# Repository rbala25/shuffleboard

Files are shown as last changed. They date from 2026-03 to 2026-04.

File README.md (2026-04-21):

# Shuffleboard

60 FPS multiplayer shuffleboard built on bare-metal C/C++ for the TM4C123 — no OS, no shortcuts. ECE319H Final Project.

---

## Highlights

**Comparator + FET Input Detection** — Puck sensing uses a custom analog comparator circuit driving an N-channel FET, with hardware debouncing and firmware-level input validation. Fast, noise-resistant, and doesn't rely on polling.

**Custom DAC + Audio** — Sound effects generated through an R-2R resistor ladder DAC feeding a discrete amplifier and speaker.

**SPI Display Pipeline** — ST7735 TFT screen handles all game state rendering and animations via SPI. Score output runs in parallel on 7-segment displays driven by 74HC595 shift registers.

**Game Loop & State Machine** — Fully interrupt-driven architecture managing turn logic, collision validation, and score tracking in real time. All rendering, input, and audio synchronized to a 60 FPS Timer12 interrupt — no RTOS, no scheduler.

**Mixed-Signal PCB** — Custom board with split digital/analog ground planes, decoupling for stable SPI, and an integrated comparator/FET sensing front-end alongside the DAC output stage.

---

## Stack

| Layer | Tech |
|---|---|
| MCU | TM4C123GXL (ARM Cortex-M4) |
| Language | C/C++, bare-metal |
| Display | ST7735 TFT over SPI |
| Score Display | 7-segment + 74HC595 shift registers |
| Audio | R-2R DAC + speaker amp |
| Input | Analog comparator + N-FET + hardware debounce |

---

Developed for **ECE319H — Introduction to Embedded Systems (Honors)** at The University of Texas at Austin.

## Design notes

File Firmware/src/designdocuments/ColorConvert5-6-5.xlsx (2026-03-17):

red | green | blue | 565
0 | 255 | 120 | 0x7FE0 | 0x7FE0, // 0, 255, 120

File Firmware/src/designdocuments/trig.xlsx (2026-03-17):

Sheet: 64
 | 2 |  | 64
angle | vx | vy | ix | iy
0 | 2 | 0 | 128 | 0
0.09817477042 | 1.990369453 | 0.1960342807 | 127 | 13
0.1963495408 | 1.961570561 | 0.390180644 | 126 | 25
0.2945243113 | 1.913880671 | 0.5805693545 | 122 | 37
0.3926990817 | 1.847759065 | 0.7653668647 | 118 | 49
0.4908738521 | 1.763842529 | 0.9427934737 | 113 | 60
0.5890486225 | 1.662939225 | 1.111140466 | 106 | 71
0.687223393 | 1.546020907 | 1.268786568 | 99 | 81
0.7853981634 | 1.414213562 | 1.414213562 | 91 | 91
0.8835729338 | 1.268786568 | 1.546020907 | 81 | 99
0.9817477042 | 1.111140466 | 1.662939225 | 71 | 106
1.079922475 | 0.9427934737 | 1.763842529 | 60 | 113
1.178097245 | 0.7653668647 | 1.847759065 | 49 | 118
1.276272016 | 0.5805693545 | 1.913880671 | 37 | 122
1.374446786 | 0.390180644 | 1.961570561 | 25 | 126
1.472621556 | 0.1960342807 | 1.990369453 | 13 | 127
1.570796327 | -7.656635742e-16 | 2 | 0 | 128
1.668971097 | -0.1960342807 | 1.990369453 | -13 | 127
1.767145868 | -0.390180644 | 1.961570561 | -25 | 126
1.865320638 | -0.5805693545 | 1.913880671 | -37 | 122
1.963495408 | -0.7653668647 | 1.847759065 | -49 | 118
2.061670179 | -0.9427934737 | 1.763842529 | -60 | 113
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

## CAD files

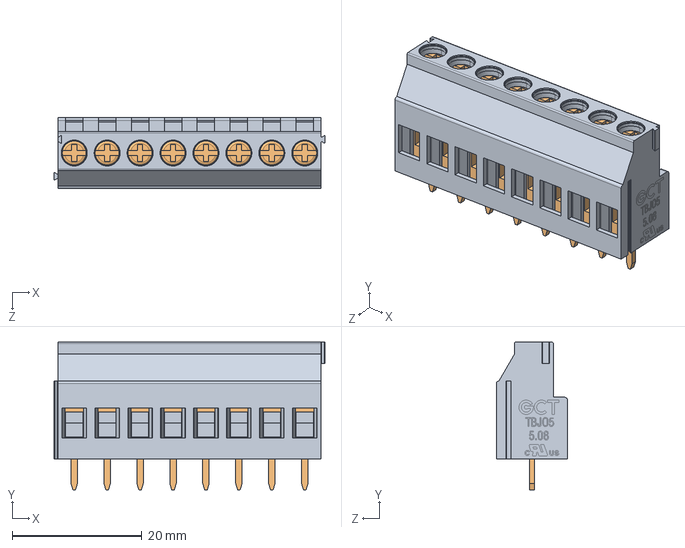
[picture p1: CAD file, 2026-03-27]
Hardware/Shuffleboard/SpecificParts/3D/TBJ05-08-1-G-G.stp
41.8 x 22.8 x 11.0 mm

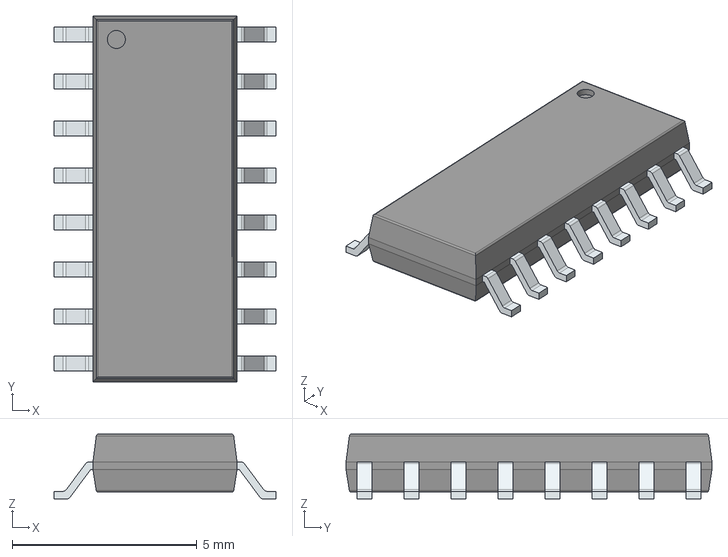
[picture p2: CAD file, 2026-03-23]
Hardware/Shuffleboard/SpecificParts/3D/74HC595D_BJ_.stp
6.00 x 9.90 x 1.75 mm
PinsArrayLR

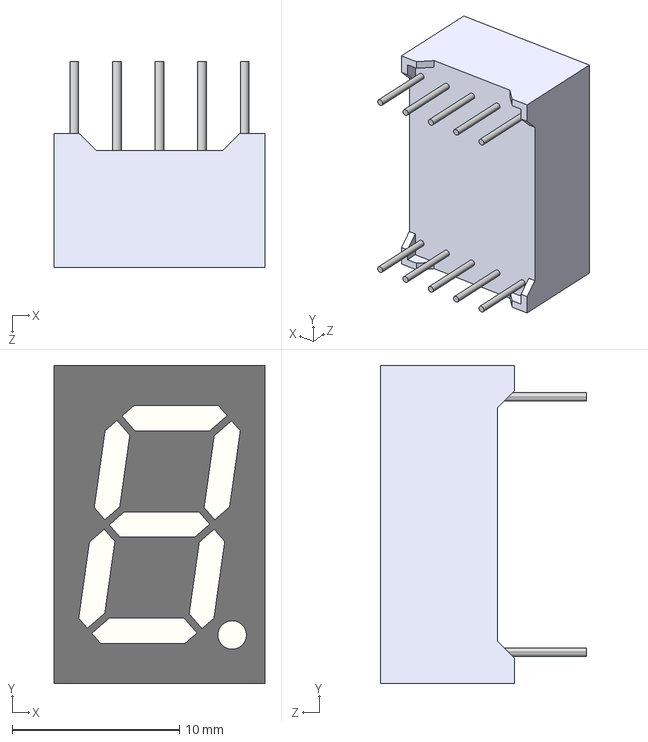
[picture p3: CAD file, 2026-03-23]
Hardware/Shuffleboard/SpecificParts/3D/INND-TS56RCB.stp
12.6 x 19.0 x 12.3 mm

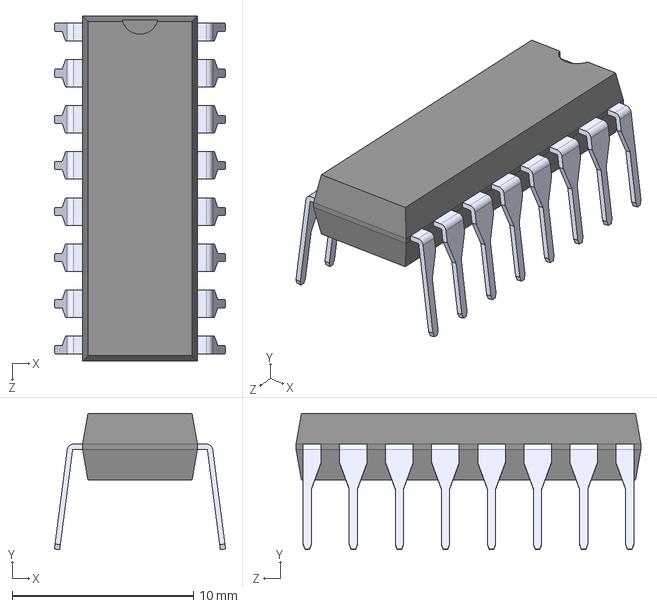
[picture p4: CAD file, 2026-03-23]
Hardware/Shuffleboard/SpecificParts/3D/LOGIC-74HC595N_DIP16_.step
9.44 x 7.53 x 19.0 mm

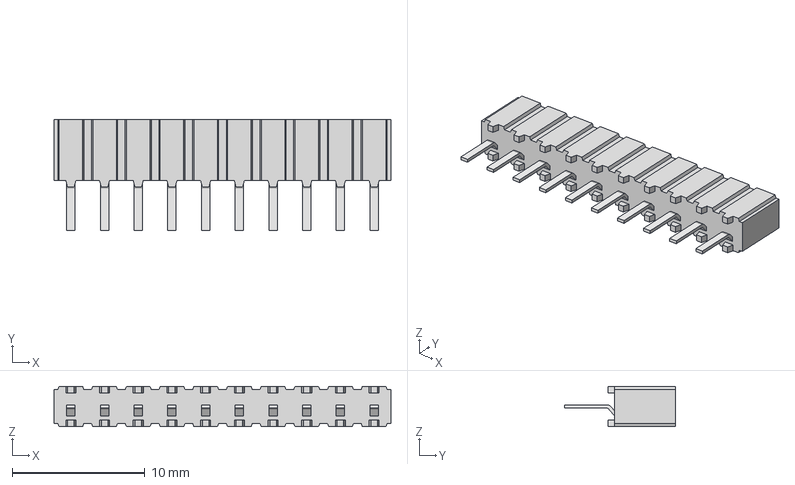
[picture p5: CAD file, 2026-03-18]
Hardware/Shuffleboard/SpecificParts/3D/CES-110-01-G-S.stp
25.4 x 8.33 x 3.05 mm
CES-110-01-S_socket
011001TS
011001TS2

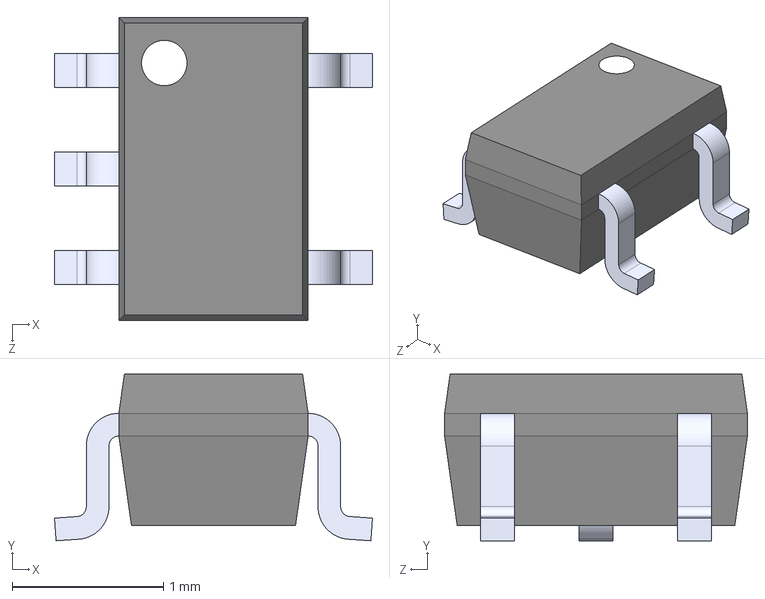
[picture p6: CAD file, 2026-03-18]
Hardware/Shuffleboard/SpecificParts/3D/LMV331M7.STEP
2.10 x 1.10 x 2.00 mm

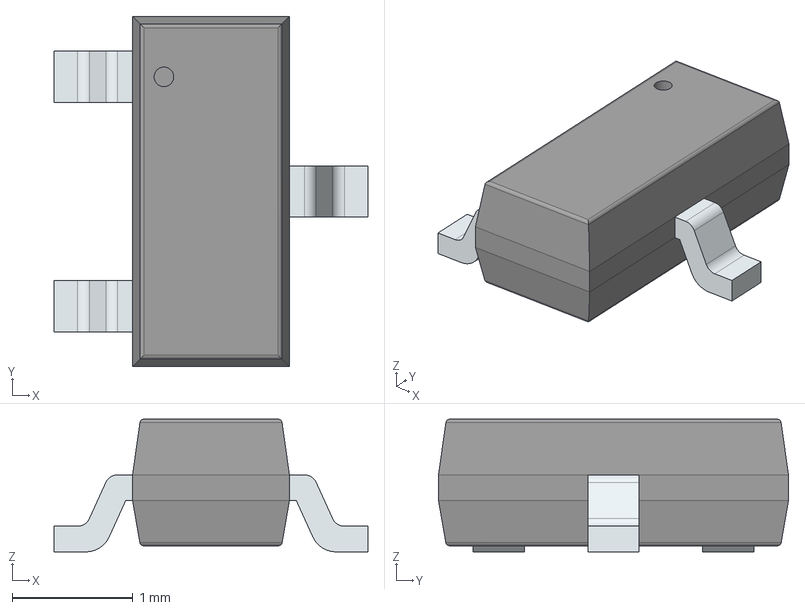
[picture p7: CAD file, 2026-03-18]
Hardware/Shuffleboard/SpecificParts/3D/2N7002_H6327.stp
2.60 x 2.90 x 1.10 mm
PinsArrayL
FilletPinR

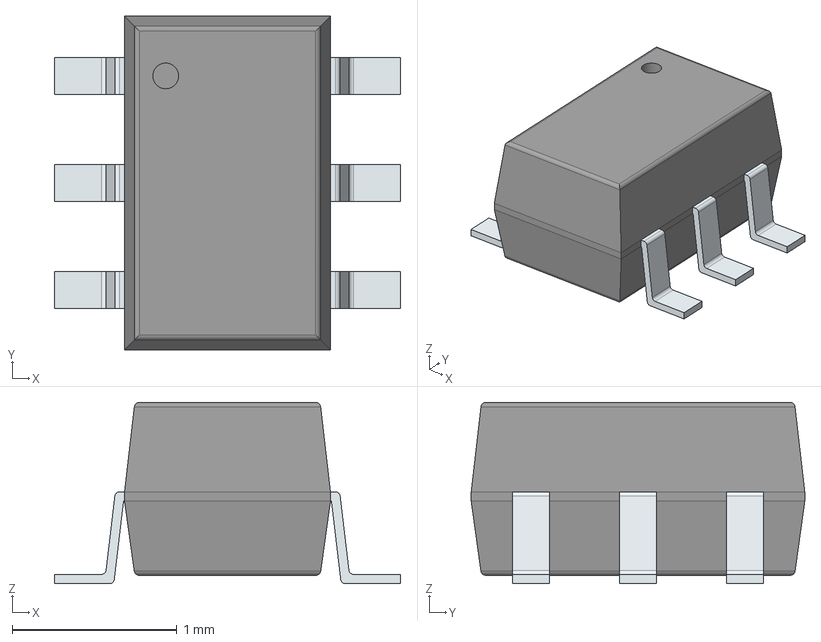
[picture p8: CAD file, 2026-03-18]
Hardware/Shuffleboard/SpecificParts/3D/DG3157EDL-T1-GE3.stp
2.10 x 2.02 x 1.10 mm
PinsArrayLR

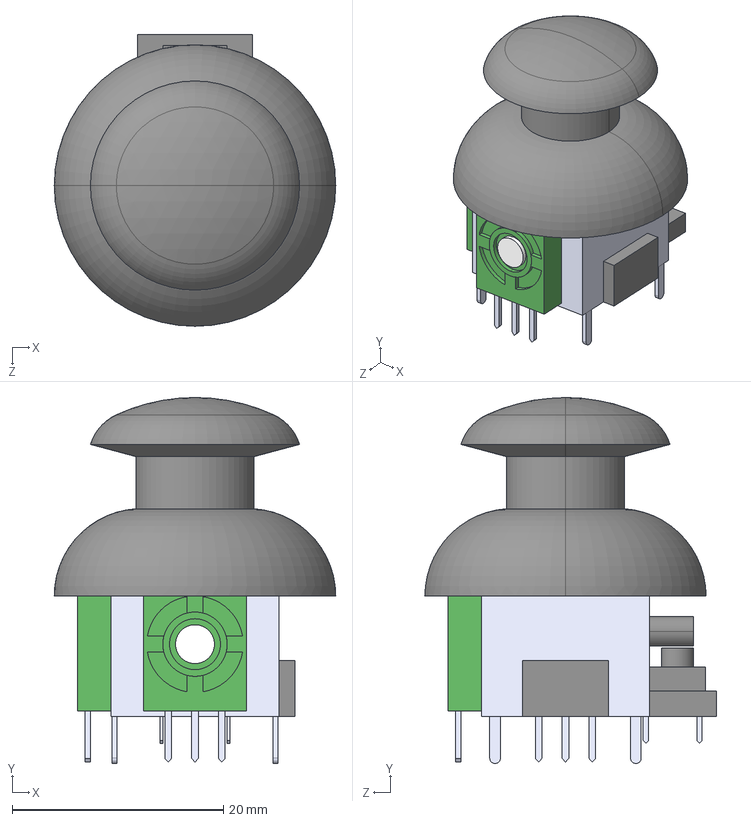
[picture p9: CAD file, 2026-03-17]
Hardware/Shuffleboard/SpecificParts/3D/COM-09032.step
26.7 x 34.7 x 27.6 mm

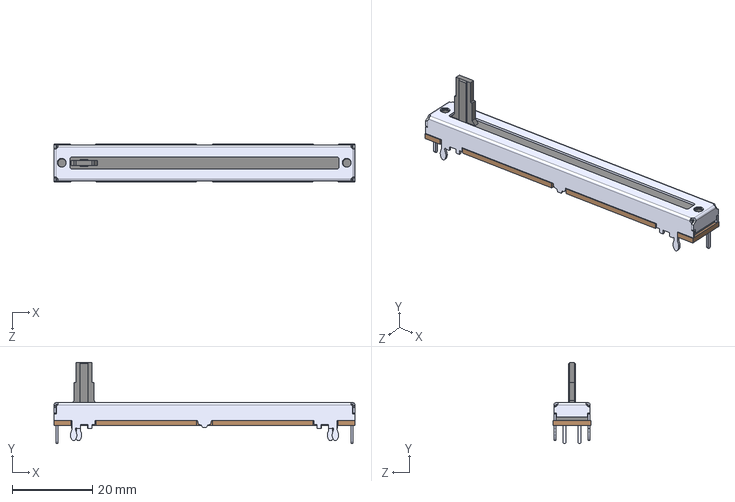
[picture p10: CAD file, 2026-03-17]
Hardware/Shuffleboard/SpecificParts/3D/PTA6043-2010CIA203.STEP
75.0 x 20.2 x 9.40 mm

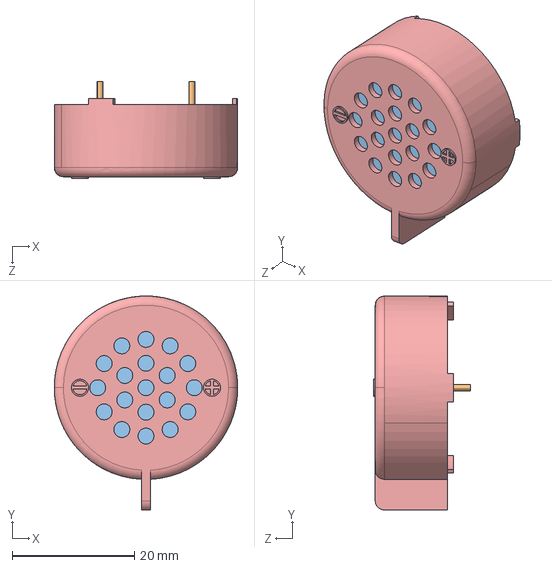
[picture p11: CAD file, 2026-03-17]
Hardware/Shuffleboard/SpecificParts/3D/CMS-3012-18T.STEP
30.0 x 35.0 x 15.9 mm

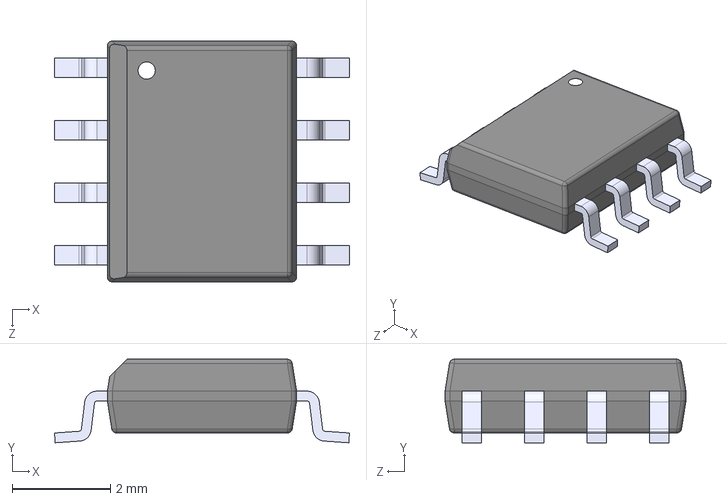
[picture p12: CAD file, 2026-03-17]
Hardware/Shuffleboard/SpecificParts/3D/PAM8302AADCR.step
6.00 x 1.70 x 4.90 mm

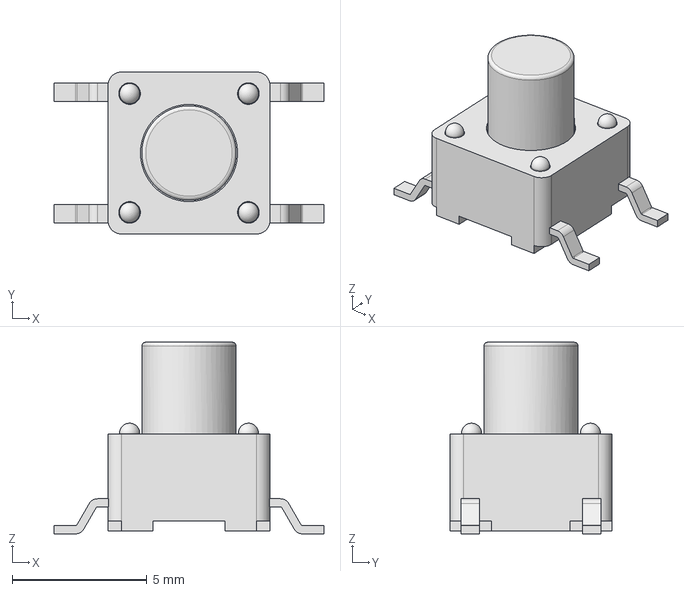
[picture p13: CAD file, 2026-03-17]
Hardware/Shuffleboard/SpecificParts/3D/TL3301FF160QG.STEP
10.0 x 6.00 x 7.10 mm

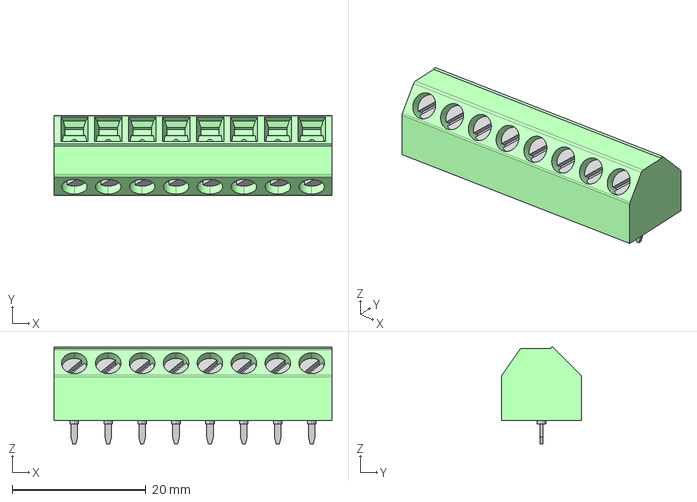
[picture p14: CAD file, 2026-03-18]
Hardware/Shuffleboard/SpecificParts/3D/1869279.stp
41.6 x 12.0 x 14.5 mm

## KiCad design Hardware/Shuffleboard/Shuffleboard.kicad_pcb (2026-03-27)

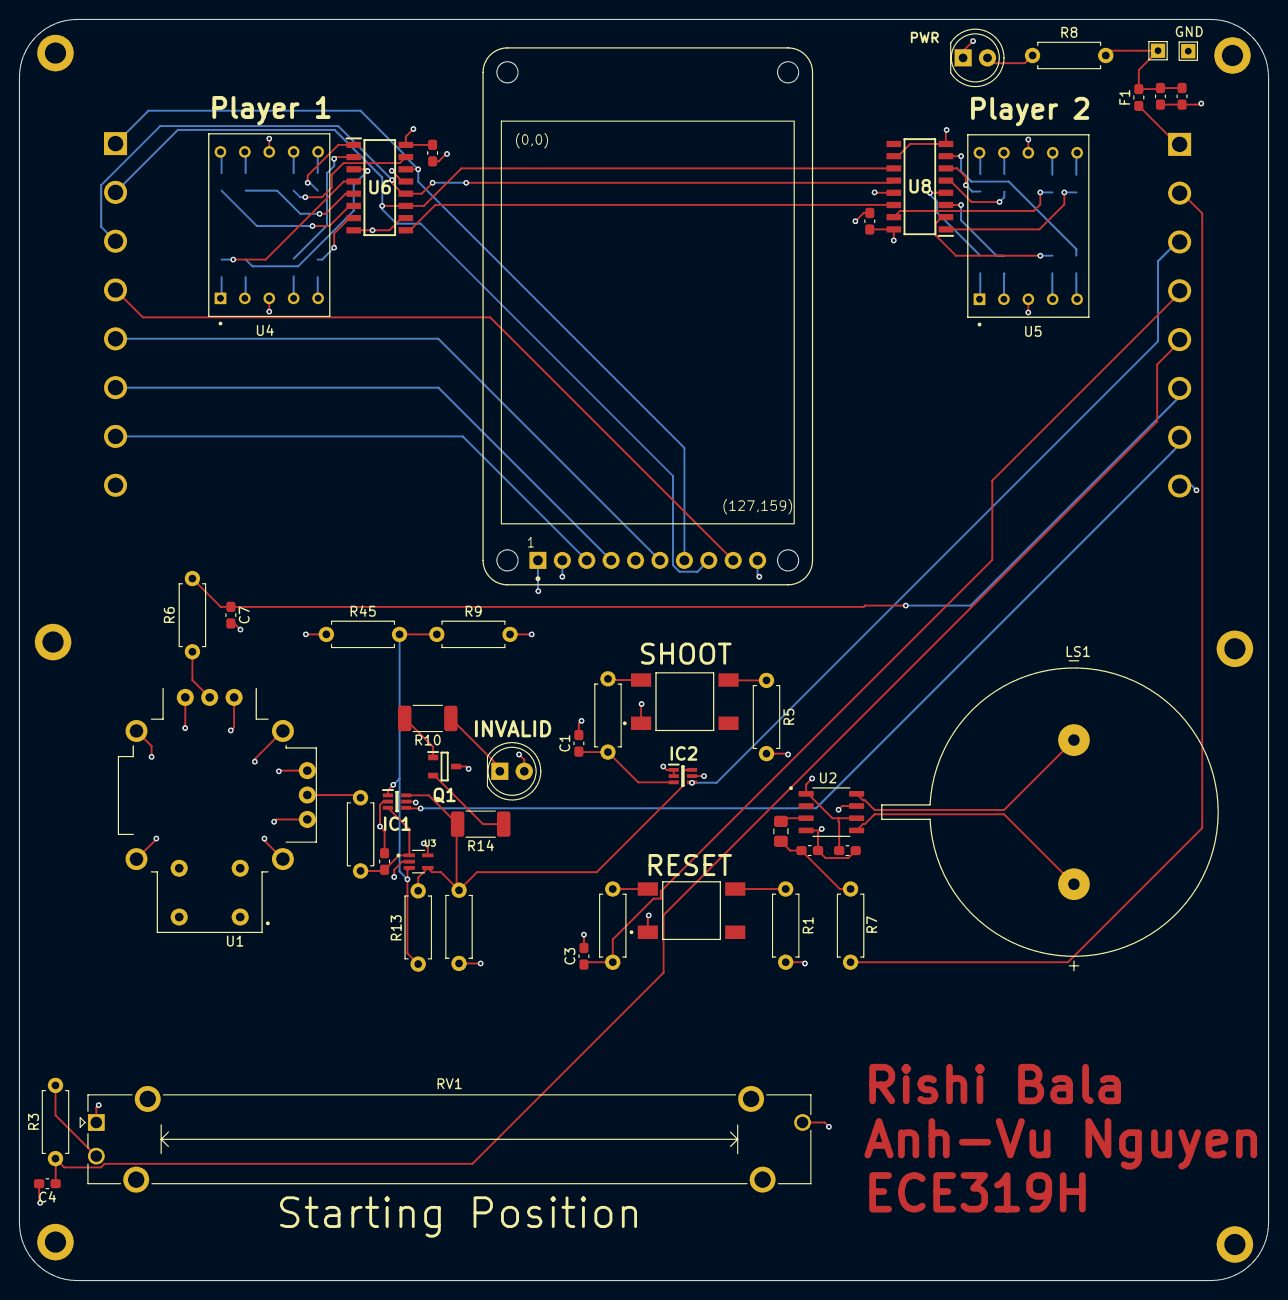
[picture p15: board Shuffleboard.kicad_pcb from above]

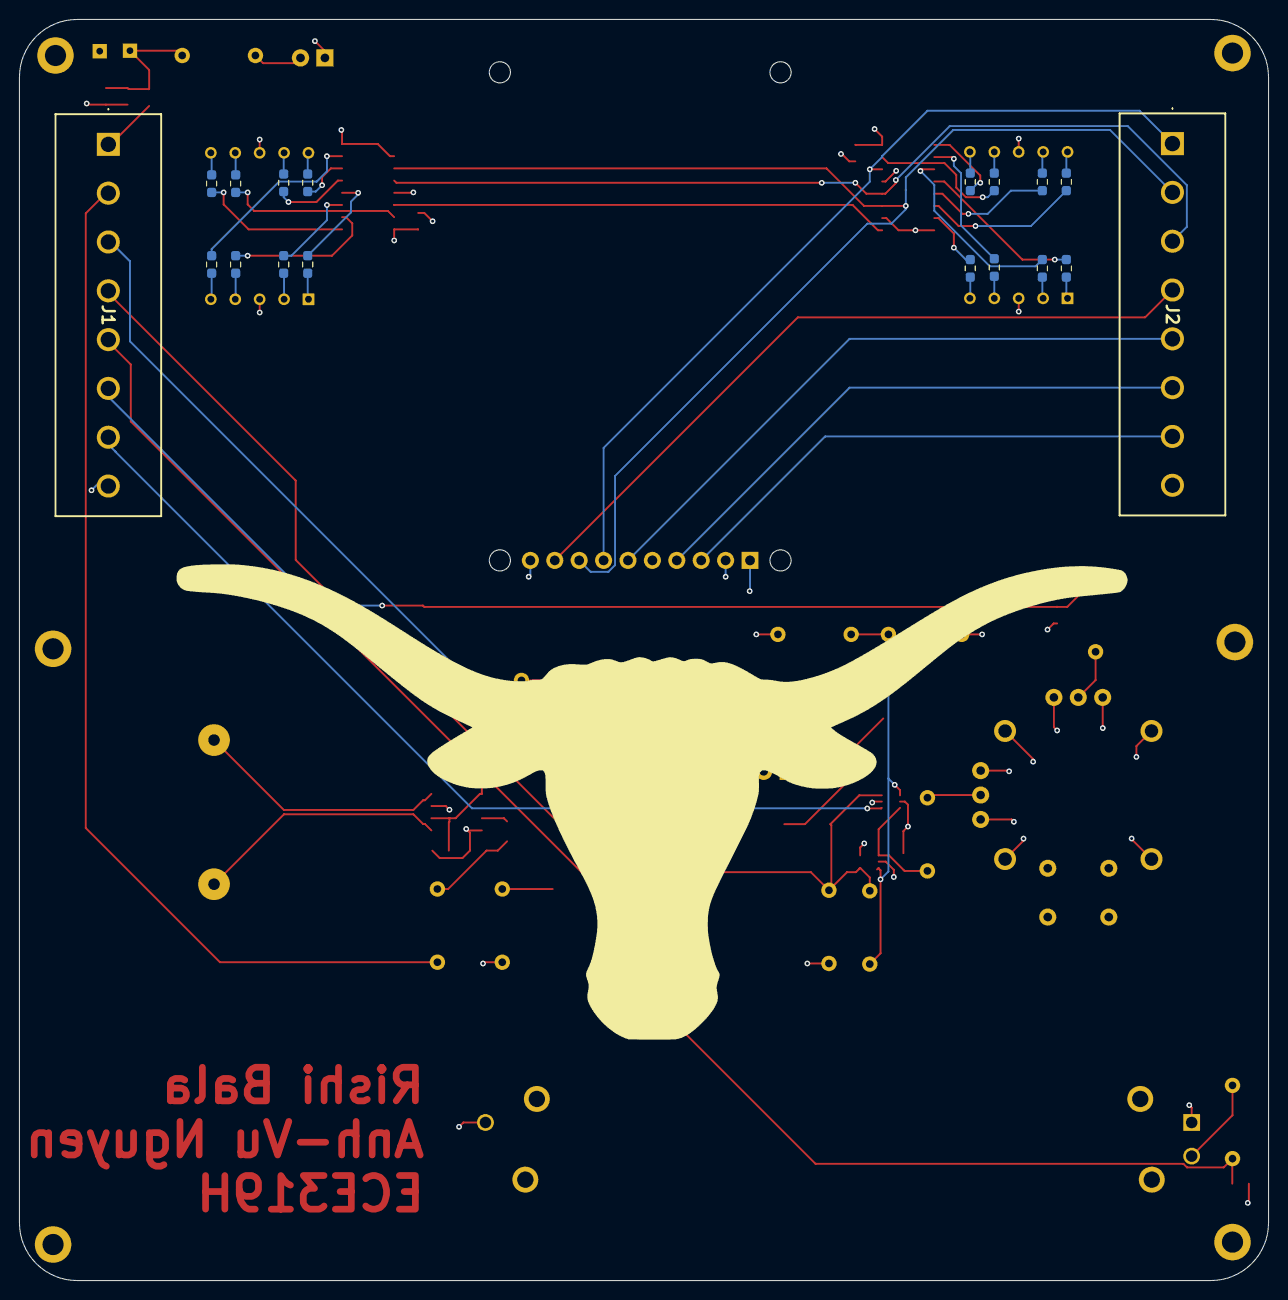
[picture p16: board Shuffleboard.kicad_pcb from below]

Board: 4 copper layers, 130.0 x 131.2 mm, 71 parts (18 on the bottom side), 68 nets.

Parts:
C1, C2, C3, C4, C5, C6, C7, C8, C10, C11, C12: 100n; C_0603_1608Metric_Pad1.08x0.95mm_HandSolder
C9: 1u; C_0805_2012Metric_Pad1.18x1.45mm_HandSolder
D1: Red; LED_D5.0mm
D32: Green; LED_D5.0mm
F1: Fuse_0603_1608Metric_Pad1.05x0.95mm_HandSolder
H1, H2, H3, H4, H5, H6: MountingHole_2.2mm_M2_DIN965_Pad
IC1, IC2: SOT65P210X110-6N
J1, J2: TBJ05-08-1-G-G; TBJ05081GG
LS1: SPKR_CMS-3012-18T
Q1: SOT95P260X110-3N
R1, R5, R9, R12, R13, R45: 10k; R_Axial_DIN0207_L6.3mm_D2.5mm_P7.62mm_Horizontal
R2, R3, R4, R6, R7, R8, R11: 1k; R_Axial_DIN0207_L6.3mm_D2.5mm_P7.62mm_Horizontal
R10, R14: 330; R_2010_5025Metric_Pad1.40x2.65mm_HandSolder
R15, R16, R17, R18, R19, R20, R21, R22, R23, R24, R25, R26, R27, R28, R29, R30: 100; R_0603_1608Metric_Pad0.98x0.95mm_HandSolder
RV1: Potentiometer_Bourns_PTA6043_Single_Slide
S1, S2: SW_TL3301FF160QG
TP1, TP2: TestPoint_THTPad_1.5x1.5mm_Drill0.7mm
U1: XDCR_COM-09032
U2: SOIC127P600X170-8N
U3: Comparator; lmv331
U4, U5: LED_INND-TS56RCB
U6, U8: SOIC127P600X175-16N
U7: adafruit_st7735r

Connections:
+3.3V: C2.1, C6.2, C10.2, C11.2, C12.1, D1.2 (A), F1.2, IC1.5 (V+), IC2.5 (V+), R8.2, R12.1, R45.1, RV1.1, S1.1, S2.1, TP2.1 (1_1), U1.H1 (H+), U1.V1 (V+), U2.1 (~SD), U2.6 (VDD), U3.5 (V+), U6.13 (G), U6.16 (VCC), U7.2 (VCC), U7.10 (LITE), U8.13 (G), U8.16 (VCC)
/3.3VIN: F1.1, J1.1
/7Seg/QH1: U6.9 (QH*), U8.14 (SER)
/Connector/HOR_PB18_ADC1_5: C7.1, J1.6, R6.2
/Connector/POS_PB17_ADC1_4: C4.1, J1.5, R3.2
/Connector/VER_PB19_ADC1_6: IC1.4 (A), J1.7
/DACOut: J1.2, R7.1
/Inputs/CompOut: IC1.6 (S), IC2.6 (S), R12.2, R13.2, R14.2, U3.4
/Inputs/SHOOT_SW: C1.1, IC2.3 (B0), R11.2
/Inputs/VER_POT: C5.1, IC1.3 (B0), R4.2, U3.1 (+)
/Inputs/Vref: IC1.1 (B1), R9.1, R13.1, R45.2, U3.3 (-)
/PA13_DC: J2.6, U7.4 (D/C)
/PB1RST: C3.1, J1.4, R2.2
/PB4SHOOT: IC2.4 (A), J1.3
/PB6_CS: J2.5, U7.6 (TFT_CS)
/PB7_MISO: J2.4, U7.9 (MISO)
/PB8_MOSI: J2.1, U6.14 (SER), U7.7 (MOSI)
/PB9_SPI_CLK: J2.2, U6.11 (SCK), U7.8 (SCK), U8.11 (SCK)
/PB15_RESET: J2.7, U7.3 (RESET)
/PB16_L/P: J2.3, U6.12 (RCK), U8.12 (RCK)
/Speaker/OUT+: LS1.P, U2.5 (OUT+)
/Speaker/OUT-: LS1.N, U2.8 (OUT-)
GND: C1.2, C2.2, C3.2, C4.2, C5.2, C6.1, C7.2, C8.2, C10.1, C11.1, C12.2, D32.1 (K), IC1.2 (GND), IC2.1 (B1), IC2.2 (GND), J1.8, J2.8, Q1.3 (S), R1.2, R5.2, R9.2, RV1.3, TP1.1 (1_1), U1.H3 (H-), U1.S1 (SHIELD), U1.S2 (SHIELD), U1.S3 (SHIELD), U1.S4 (SHIELD), U1.V3 (V-), U2.4 (IN-), U2.7 (GND), U3.2 (V-), U4.3, U4.8, U5.3, U5.8, U6.8 (GND), U6.10 (SCL), U7.1 (GND), U8.8 (GND), U8.10 (SCL)
unnamed: C8.1, C9.1, R7.2
unnamed: D1.1 (K), R10.1
unnamed: D32.2 (A), R8.1
unnamed: Q1.1 (D), R10.2
unnamed: Q1.2 (G), R14.1
unnamed: R1.1, S2.4
unnamed: R2.1, S2.3
unnamed: R3.1, RV1.2
unnamed: R5.1, S1.4
unnamed: R11.1, S1.3
unnamed: R15.2, U4.7
unnamed: R16.2, U4.6
unnamed: R17.2, U4.4
unnamed: R18.2, U4.2
unnamed: R19.2, U4.1
unnamed: R20.2, U4.9
unnamed: R21.2, U4.10
unnamed: R22.2, U4.5
unnamed: R23.2, U5.7
unnamed: R24.2, U5.6
unnamed: R25.2, U5.4
unnamed: R26.2, U5.2
unnamed: R27.2, U5.1
unnamed: R28.2, U5.9
unnamed: R29.2, U5.10
unnamed: R30.2, U5.5
unnamed: R6.1, U1.H2 (H)
unnamed: R4.1, U1.V2 (V)
unnamed: C9.2, U2.3 (IN+)
unnamed: R15.1, U6.15 (QA)
unnamed: R16.1, U6.1 (QB)
unnamed: R17.1, U6.2 (QC)
unnamed: R18.1, U6.3 (QD)
unnamed: R19.1, U6.4 (QE)
unnamed: R20.1, U6.5 (QF)
unnamed: R21.1, U6.6 (QG)
unnamed: R22.1, U6.7 (QH)
unnamed: R23.1, U8.15 (QA)
unnamed: R24.1, U8.1 (QB)
unnamed: R25.1, U8.2 (QC)
unnamed: R26.1, U8.3 (QD)
unnamed: R27.1, U8.4 (QE)
unnamed: R28.1, U8.5 (QF)
unnamed: R29.1, U8.6 (QG)
unnamed: R30.1, U8.7 (QH)

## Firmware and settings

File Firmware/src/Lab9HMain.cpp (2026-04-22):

// Lab9HMain.cpp
// Runs on MSPM0G3507
// Lab 9 ECE319H
// Anh-Vu Nguyen, Rishi Bala
// Last Modified: January 12, 2026

#include <stdio.h>
#include <stdint.h>
#include <ti/devices/msp/msp.h>
#include "../inc/ST7735.h"
#include "../inc/Clock.h"
#include "../inc/LaunchPad.h"
#include "../inc/TExaS.h"
#include "../inc/Timer.h"
#include "../inc/SlidePot.h"
#include "../inc/DAC.h"
#include "SmallFont.h"
#include "LED.h"
#include "Switch.h"
#include "Sound.h"
#include "images/images.h"
#include "Graphics.h"
#include "Puck.h"
#include "Button.h"
#include "../inc/ADC1.h"
#include "../inc/ADC1.c"
#include "ScoreDisplay.h"
extern "C" void __disable_irq(void);
extern "C" void __enable_irq(void);
extern "C" void TIMG12_IRQHandler(void);

extern volatile uint32_t ShootFlag;
extern volatile uint32_t ResetFlag;
volatile uint32_t SemaphoreFlag = 0;
volatile float aim = 0.0f;
volatile float power = 0.0f;
volatile float start = 0.0f;

volatile uint8_t redScore;
volatile uint8_t blueScore;

void PLL_Init(void){
  Clock_Init80MHz(0);
}

Puck pArray[6] = {
  Puck(60,165,"Red",0), Puck(60,165,"Blue",1),
  Puck(60,165,"Red",2), Puck(60,165,"Blue",3),
  Puck(60,165,"Red",4), Puck(60,165,"Blue",5)
};

uint32_t M=1;
uint32_t Random32(void){ M = 1664525*M+1013904223; return M; }
uint32_t Random(uint32_t n){ return (Random32()>>16)%n; }

SlidePot Sensor(1500,0);

// physics + ADC only
// no game state, no flag clearing
void TIMG12_IRQHandler(void){
  if((TIMG12->CPU_INT.IIDX) == 1){
    GPIOB->DOUTTGL31_0 = GREEN;
    // 1) sample joystick ADC

    float rawAim, rawStart;
    uint8_t vertError;
    ADCin(&rawStart, &rawAim, &power, &vertError);
    aim   = rawAim * 2.0f - 1.0f;
    rawStart = sqrtf(rawStart);
    float newStart = rawStart * 2.0f - 1.0f;
    start = start * 0.5f + newStart * 0.5f; //estimated moving average formula

    // 2) move sprites
    for(int i = 0; i < 6; i++){
      if(pArray[i].isMoving)
        pArray[i].process_Movement();
    }

    // 3) signal main — NO LCD OUTPUT IN INTERRUPT SERVICE ROUTINES
    SemaphoreFlag = 1;
    GPIOB->DOUTTGL31_0 = GREEN;
  }
}

uint8_t TExaS_LaunchPadLogicPB27PB26(void){
  return (0x80|((GPIOB->DOUT31_0>>26)&0x03));
}

typedef enum {English, Spanish, Portuguese, French} Language_t;
Language_t myLanguage=English;
typedef enum {HELLO, GOODBYE, LANGUAGE} phrase_t;
const char Hello_English[] ="Hello";
const char Hello_Spanish[] ="\xADHola!";
const char Hello_Portuguese[] = "Ol\xA0";
const char Hello_French[] ="All\x83";
const char Goodbye_English[]="Goodbye";
const char Goodbye_Spanish[]="Adi\xA2s";
const char Goodbye_Portuguese[] = "Tchau";
const char Goodbye_French[] = "Au revoir";
const char Language_English[]="English";
const char Language_Spanish[]="Espa\xA4ol";
const char Language_Portuguese[]="Portugu\x88s";
const char Language_French[]="Fran\x87" "ais";
// const char *Phrases[3][4]={
//   {Hello_English,Hello_Spanish,Hello_Portuguese,Hello_French},
//   {Goodbye_Englifsh,Goodbye_Spanish,Goodbye_Portuguese,Goodbye_French},
//   {Language_English,Language_Spanish,Language_Portuguese,Language_French}
// };

typedef enum { LANGUAGE_SELECT, AIMING, SHOOTING, SCORING, GAME_OVER } GameState_t;
uint8_t language = 0;  // 0=English, 1=French

static bool allStopped(void){
  for(int i = 0; i < 6; i++)
    if(pArray[i].isMoving) return false;
  return true;
}

// ALL ST7735 OUTPUT MUST OCCUR IN MAIN
int main(void){
  __disable_irq();
  PLL_Init();
  LaunchPad_Init();
  graphics_init();
  Sensor.Init();
  ADCinit();
  Button_Init();
  LED_Init();
  Sound_Init();
  TExaS_Init(0,0,&TExaS_LaunchPadLogicPB27PB26);
  TimerG12_IntArm(2666667, 3);  // 80MHz/2666667 = 30fps
  __enable_irq();
  scoreDisplay_init();
  drawLanguageScreen(language);

  GameState_t state = LANGUAGE_SELECT;
  uint8_t activePuck = 0;  // 0-5
  float prevAim = 0.0f, prevPower = 0.0f;

  while(1){
    while(!SemaphoreFlag){};
    SemaphoreFlag = 0;

    if(ResetFlag){
      ResetFlag = 0;
      ShootFlag = 0;
      if(state == LANGUAGE_SELECT){
        language ^= 1;
        drawLanguageScreen(language);
      } else {
        if(state == AIMING)
          drawArrow(pArray[activePuck].x, pArray[activePuck].y, prevAim, prevPower, true);
        pArray[0] = Puck(60,165,"Red",0);
        pArray[1] = Puck(60,165,"Blue",1);
        pArray[2] = Puck(60,165,"Red",2);
        pArray[3] = Puck(60,165,"Blue",3);
        pArray[4] = Puck(60,165,"Red",4);
        pArray[5] = Puck(60,165,"Blue",5);
        activePuck = 0;
        prevAim = 0.0f; prevPower = 0.0f;
        redScore = 0; blueScore = 0;
        updateScoreDisplay(0, 0);
        drawLanguageScreen(language);
        state = LANGUAGE_SELECT;
      }
    }

    switch(state){

      case LANGUAGE_SELECT:
        if(ShootFlag){
          ShootFlag = 0;
          drawBackground();
          state = AIMING;
        }
        break;

      case AIMING: {
        // erase arrow at current puck position before sliding
        drawArrow(pArray[activePuck].x, pArray[activePuck].y, prevAim, prevPower, true);

        // slide active puck left/right with start pot
        {
          float newX = (start + 1.0f) * 0.5f * 113.0f;
          if(newX < 0.0f) newX = 0.0f;
          if(newX > 113.0f) newX = 113.0f;
          pArray[activePuck].oldX = pArray[activePuck].x;
          pArray[activePuck].oldY = pArray[activePuck].y;
          pArray[activePuck].x = newX;
          pArray[activePuck].y = 125.0f;
        }

        float clampedAim = aim;
        if(clampedAim >  0.90f) clampedAim =  0.90f;
        if(clampedAim < -0.90f) clampedAim = -0.90f;

        // draw arrow at new puck position
        drawArrow(pArray[activePuck].x, pArray[activePuck].y, clampedAim, power, false);
        prevAim   = clampedAim;
        prevPower = power;

        if(ShootFlag){
          ShootFlag = 0;
          if(power > 0.1) {
            // erase arrow, switch state
            drawArrow(pArray[activePuck].x, pArray[activePuck].y, prevAim, prevPower, true);
            float angle = prevAim * (3.14159f / 2.0f);
            pArray[activePuck].set_Velocity(sinf(angle) * prevPower * 12.0f, -cosf(angle) * prevPower * 7.0f);
            prevAim = 0.0f; prevPower = 0.0f;
            Sound_Shoot();
            state = SHOOTING;
          }
        }
        break;
      }

      case SHOOTING:
        if(allStopped()){
          state = SCORING;
        }
        break;

      case SCORING:
        Sound_Collision();
        calculateScore((uint8_t*)&redScore, (uint8_t*)&blueScore, pArray);
        updateScoreDisplay(redScore, blueScore);
        activePuck++;
        if(activePuck >= 6){
          Sound_Winner();
          drawBackground();
          drawWinnerBanner(redScore, blueScore, language);
          state = GAME_OVER;
        } else {
          ShootFlag = 0;
          state = AIMING;
        }
        break;

      case GAME_OVER:
        // waiting for reset 
        break;
    }

    // render pucks every frame
    if(state != GAME_OVER && state != LANGUAGE_SELECT){
      for(int i = 0; i < 6; i++){
        renderPuck(pArray[i]);
      }
    }

    if(state == AIMING){
      pArray[activePuck].oldX = pArray[activePuck].x;
      pArray[activePuck].oldY = pArray[activePuck].y;
    }
  }
}

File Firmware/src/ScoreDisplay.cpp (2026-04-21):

#include "ScoreDisplay.h"
#include <ti/devices/msp/msp.h>
#include "../inc/ST7735.h"
#include "../inc/LaunchPad.h"
#include "Graphics.h"
#include "images/images.h"

//  SPI is MSB-first: bit7 sent first → reaches QH; bit0 sent last → reaches QA
//  Wiring: QA→A, QB→B, QC→C, QD→D, QE→E, QF→F, QG→G, QH→DP
//  So: bit0=A, bit1=B, bit2=C, bit3=D, bit4=E, bit5=F, bit6=G, bit7=DP
//
//      AAA
//     F   B
//     F   B
//      GGG
//     E   C
//     E   C
//      DDD  [DP]
//
static const uint8_t SEG7[10] = {
    0x3F,  // 0: A B C D E F
    0x06,  // 1:   B C
    0x5B,  // 2: A B   D E   G
    0x4F,  // 3: A B C D     G
    0x66,  // 4:   B C     F G
    0x6D,  // 5: A   C D   F G
    0x7D,  // 6: A   C D E F G
    0x07,  // 7: A B C
    0x7F,  // 8: A B C D E F G
    0x6F,  // 9: A B C D   F G
};

static uint8_t s_red  = 0;
static uint8_t s_blue = 0;

static void spi_send_byte(uint8_t data) {
    while (!(SEG_SPI_BASE->STAT & SPI_STAT_TNF_MASK)); //wait for tx fifo not full
    SEG_SPI_BASE->TXDATA = data;
    while (SEG_SPI_BASE->STAT & SPI_STAT_BUSY_MASK);
}

static void latch_pulse(void) {
    GPIOB->DOUTSET31_0 = SEG_LATCH_PIN;
    __NOP(); __NOP(); __NOP(); __NOP(); __NOP(); // 5 NOPs = ~62.5ns, covers 40ns min at 3.3V
    GPIOB->DOUTCLR31_0 = SEG_LATCH_PIN;
}

// Push both score bytes to the daisy-chained 595s
// U8 data first then U6 data
static void push_to_595(uint8_t redByte, uint8_t blueByte) {
    spi_send_byte(blueByte);  
    spi_send_byte(redByte);  
    latch_pulse();
}

void scoreDisplay_init(void) {
    // PB16 latch pin - configure IOMUX as GPIO, then set as output, start low
    IOMUX->SECCFG.PINCM[PB16INDEX] = 0x00000081;
    GPIOB->DOE31_0  |=  SEG_LATCH_PIN;
    GPIOB->DOUTCLR31_0 = SEG_LATCH_PIN;

    push_to_595(SEG7[0], SEG7[0]);
    updateScoreDisplay(0, 0);
}

static void drawBigString(int16_t x, int16_t y, const char *str, uint16_t fg, uint16_t bg) {
    for (int i; *str; str++, x += 12)
        ST7735_DrawCharS(x, y, *str, fg, bg, 2);
}

static void drawSmallString(int16_t x, int16_t y, const char *str, uint16_t fg, uint16_t bg) {
    for (int i; *str; str++, x += 6)
        ST7735_DrawCharS(x, y, *str, fg, bg, 1);
}

void drawWinnerBanner(uint8_t redScore, uint8_t blueScore, uint8_t lang) {
    uint16_t bannerColor;
    const char *line1;
    int16_t textX;

    if (lang == 1) {  
        if (redScore > blueScore) {
            bannerColor = SCORE_COLOR_RED;
            line1 = "ROUGE WIN!";  
            textX = 4;
        } else if (blueScore > redScore) {
            bannerColor = SCORE_COLOR_BLUE;
            line1 = "BLEU WIN! "; 
            textX = 4;
        } else {
            bannerColor = ST7735_Color565(140, 60, 200);
            line1 = "EGALITE!";
            textX = 16;
        }
    } else {  // english
        if (redScore > blueScore) {
            bannerColor = SCORE_COLOR_RED;
            line1 = "RED WINS!";
            textX = 10;
        } else if (blueScore > redScore) {
            bannerColor = SCORE_COLOR_BLUE;
            line1 = "BLUE WINS!";
            textX = 4;
        } else {
            bannerColor = ST7735_Color565(140, 60, 200);
            line1 = "  TIE!  ";
            textX = 4;
        }
    }

    uint16_t white = ST7735_Color565(255, 255, 255);
    ST7735_FillRect(4, 56, 120, 54, bannerColor);
    drawBigString(textX, 63, line1, white, bannerColor);
    const char *sub = (lang == 1) ? "Appuyez Reset" : "Press Reset";
    drawSmallString(lang == 1 ? 15 : 31, 91, sub, white, bannerColor);
}

void updateScoreDisplay(uint8_t redScore, uint8_t blueScore) {
    if (redScore  > 9) redScore  = 9;
    if (blueScore > 9) blueScore = 9;

    s_red  = redScore;
    s_blue = blueScore;

    push_to_595(SEG7[redScore], SEG7[blueScore]);

    // draw over background pixels so there's no black box
    char rBuf[2] = { (char)('0' + redScore),  '\0' };
    char bBuf[2] = { (char)('0' + blueScore), '\0' };

    int16_t rX = SCORE_LCD_X_RED,  rY = SCORE_LCD_Y;
    int16_t bX = SCORE_LCD_X_BLUE, bY = SCORE_LCD_Y;

    ST7735_DrawCharS(rX, rY, rBuf[0], SCORE_COLOR_RED,  (uint16_t)getBackgroundPixel(rX, rY), 2);
    ST7735_DrawCharS(bX, bY, bBuf[0], SCORE_COLOR_BLUE, (uint16_t)getBackgroundPixel(bX, bY), 2);
}

static uint8_t colorToPoints(uint16_t c) {
    if (c == 0x14CF) return 3;  //green
    if (c == 0x23FF) return 2;  // orange 
    if (c == 0xA380) return 1;  // blue 
    return 0;
}

static uint8_t zonePoints(int16_t x, int16_t y) {
    uint16_t c = (uint16_t)getBackgroundPixel(x, y);
    if (c != 0xFFFF) return colorToPoints(c);
    // white = boundary
    // check neighbors and take highest score
    uint8_t best = 0;
    const int8_t dx[] = {1,-1,0,0};
    const int8_t dy[] = {0,0,1,-1};
    for (int i = 0; i < 4; i++) {
        uint16_t n = (uint16_t)getBackgroundPixel(x+dx[i], y+dy[i]);
        uint8_t pts = colorToPoints(n);
        if (pts > best) best = pts;
    }
    return best;
}

void calculateScore(uint8_t* redScore, uint8_t* blueScore, Puck* arr) {
    uint8_t newRed = 0, newBlue = 0;
    for (int i = 0; i < 6; i++) {
        Puck& p = arr[i];
        if(p.x > 127 || p.y > 159) {
          continue;
        }
        int16_t cx = (int16_t)p.x + 7;
        int16_t cy = (int16_t)p.y + 7;
        uint8_t pts = zonePoints(cx, cy);
        if (p.color == "Red") {
            newRed  += pts;
        } else {
            newBlue += pts;
        }
    }
    *redScore  = newRed;
    *blueScore = newBlue;
}

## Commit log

2026-03-17 code init, PCB prog
    [1751138.stp, 8fig.kicad_sch, CMS-3012-18T.STEP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]
2026-03-18 led's, mux
    [1751138.stp, 1869279.stp, DG3157EDL-T1-GE3.stp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]
2026-03-18 fixed inverting input
    [inputs.kicad_sch]
2026-03-18 invalid button handling
    [inputs.kicad_sch]
2026-03-18 fet led driving
    [2N7002_H6327.stp, LMV331M7.STEP, Shuffleboard.kicad_pcb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]
2026-03-18 led driving fet
    [Shuffleboard.kicad_pcb, inputs.kicad_sch]
2026-03-18 fet driving
    [CES-110-01-G-S.stp, Shuffleboard.kicad_pcb, Shuffleboard.kicad_sch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]
2026-03-18 jlc eng fee
    [Shuffleboard.kicad_pcb]
2026-03-18 series gate resistor
    [Shuffleboard.kicad_pcb, Shuffleboard.kicad_sch, inputs.kicad_sch]
2026-03-23 implemented 7-seg
    [8fig.kicad_sch, LOGIC-74HC595N_DIP16_.step, connector.kicad_sch]
2026-03-23 footprints, tracing
    [74HC595D_BJ_.stp, 8fig.kicad_sch, INND-TS56RCB.stp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]
2026-03-23 layout prep
    [Shuffleboard.kicad_pcb]
2026-03-23 layout 2
    [8fig.kicad_sch, Shuffleboard.kicad_pcb, Shuffleboard.kicad_sch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]
2026-03-23 footprint for lcd
    [Shuffleboard.kicad_pcb, screen.kicad_sch]
2026-03-24 Finished Screen
    [Shuffleboard.kicad_sch, connector.kicad_sch, screen.kicad_sch]
2026-03-27 finished layout
    [8fig.kicad_sch, Shuffleboard.kicad_pcb, Shuffleboard.kicad_sch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]
2026-03-27 tht resistors
    [8fig.kicad_sch, Shuffleboard.kicad_pcb, Shuffleboard.kicad_sch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]
2026-03-27 sent to jlc
    [Shuffleboard.kicad_pcb, bom.csv, designators.csv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]
2026-04-21 updated to end
    [8fig.kicad_sch, ColorConvert5-6-5.xlsx, Shuffleboard.kicad_sch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]

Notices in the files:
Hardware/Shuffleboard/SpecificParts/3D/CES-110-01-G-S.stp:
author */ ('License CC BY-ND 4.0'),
